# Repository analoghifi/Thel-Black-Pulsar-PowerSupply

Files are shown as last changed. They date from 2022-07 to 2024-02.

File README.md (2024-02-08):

# Thel "Black Pulsar" PowerSupply
Thel High-End "Class-A" Power Supply "Black Pulsar" (correctly: constant current parallel shunt voltage regulator)  

----
  
## Version 2013-2018:
https://web.archive.org/web/20160326152234/http://www.thel-audioworld.de/module/Class-A%20Netzteil/Blackpulsar.htm  
https://web.archive.org/web/20180819093402/http://www.thel-audioworld.de:80/module/Class-A%20Netzteil/Blackpulsar.htm  
  
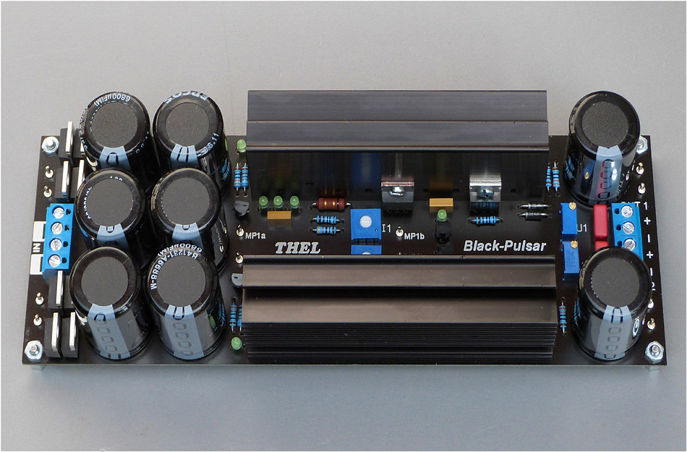
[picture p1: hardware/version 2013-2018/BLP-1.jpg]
  
  
.  
  
## Version 2019:
https://web.archive.org/web/20190630191455/http://thel-audioworld.de/module/Class-A%20Netzteil/Blackpulsar.htm  
  
### 10W:
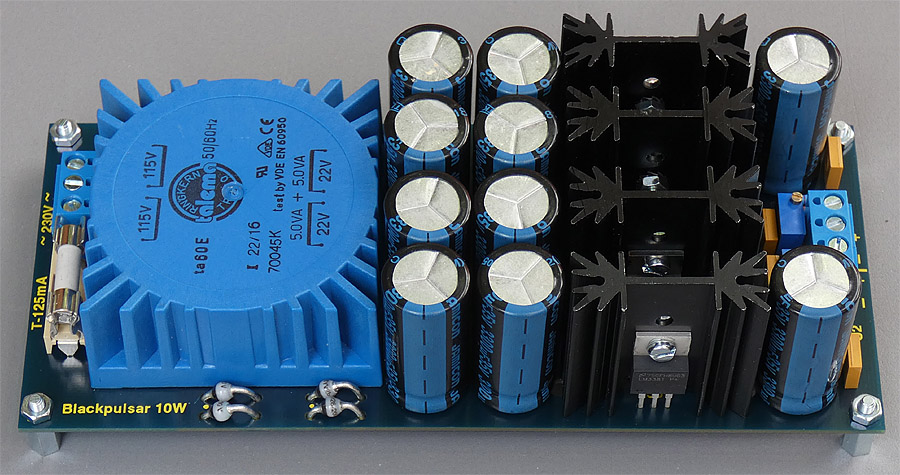
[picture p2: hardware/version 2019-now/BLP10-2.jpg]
  
  
### 25W:
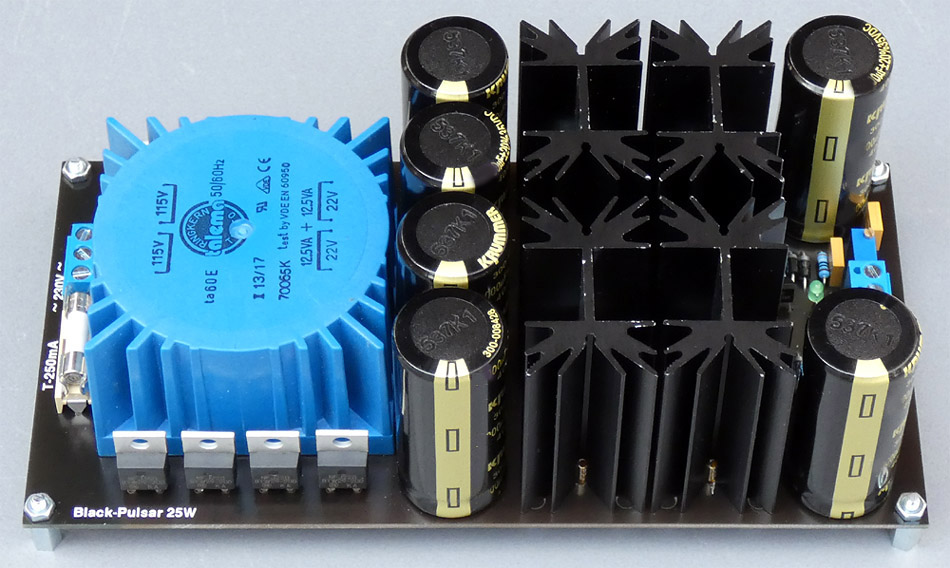
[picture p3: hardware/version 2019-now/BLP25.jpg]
  
  
----  
### Kicad projects in this repo:  
* [version 2013-2018](https://github.com/analoghifi/Thel-Black-Pulsar-PowerSupply/tree/main/hardware/version%202013-2018/KiCad/original) | state: initial release v1.01 | like the original, 1-layer, THT
*  [Black Pulsar 10W](https://github.com/analoghifi/Thel-Black-Pulsar-PowerSupply/tree/main/hardware/version%202019-now/10W/KiCad) (version 2019) | state: coming soon... | like the original, 1-layer, THT
*  [Black Pulsar 25W](https://github.com/analoghifi/Thel-Black-Pulsar-PowerSupply/tree/main/hardware/version%202019-now/25W/KiCad) (version 2019) | state: coming soon... | like the original, 1-layer, THT

----

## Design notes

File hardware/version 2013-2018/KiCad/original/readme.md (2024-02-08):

this is not the original Thel PCB but it's very like\* the original with the following exceptions:  
* more massive ground and power supply PCB tracks  
* using the 2mm gold-plated brass solder pins (the same ones used on the more expensive Thel modules)
* using a combined 5.0mm/7.5mm pin spacing footprint for the foil caps (C7,C14)  
* using a combined 2.5mm/5.0mm pin spacing footprint for the small ceramic caps (C4,C5,C11,C12)  
  
\*(same schematic / same 1-layer\** layout THT / same THT components in the same places on the board)  
\**(strictly speaking, this KiCad PCB is a two-layer PCB with plated-through holes, but you can also (let) produce it as a classic 1-layer PCB with non-plated holes if you wish, since all the tracks are on the bottom side only)  
  
----  
  
these are KiCad 6.x projects  
see how to get the proper 3D-Models from here: https://github.com/analoghifi/KiCad-3D-Models

use kicanvas.org to see this KiCad-Project in your browser:
https://kicanvas.org/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

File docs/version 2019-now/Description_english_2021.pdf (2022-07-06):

basics (https://web.archive.org/web/20210304224601/http://www.thel-audioworld.de/module/Netzteil/Infos.htm)

There are hardly any measurable hum or noise voltages or other interference components at the output. Also, not a single measure to compensate for the tendency to oscillate is necessary, as is often the case with line voltage-regulated power supplies.

Double power
pack The power pack is doubled up, the voltage of both halves can be adjusted separately and can be used individually. For operation on our audio modules, the two outputs are connected in series, which results in the required symmetrical operating voltage (https://web.archive.org/web/20210304224601/http://www.thel-audioworld.de/module/Netzteil/Infos.htm) (eg +/-18V).

weight

As a reward, a hitherto unfulfillable wishful thinking seems to have been achieved - a voltage in battery quality, in terms of freedom from interference and audiophile behavior.

Info on the electrolytic capacitor temperature: The electrolytic capacitors are selected LOW-ESR 105° types. At a cooler temperature of approx. 85° degrees, the electrolytic capacitor temperature levels off at approx. 50° degrees.

internal

audio modules (https://web.archive.org/web/20210304224601/http://www.thel-audioworld.de/module/module.htm)

Waste of energy in its purest form While conventional
analog power supplies only deliver as much current as the consumer draws, the maximum possible current flows constantly here, which is "consumed" by a load resistance and which at the same time keeps the output voltage constant. If the consumer draws current, this is shared with the load resistance, since the same current always flows through the constant current source. This switching principle is comparable to a car that is driven at full throttle and the speed is only controlled with the brakes. As a result, this "waste of energy" causes the power supply's cooler to get very hot, with the temperature dropping as the load draws more current. Since this circuit technology offers very special advantages in terms of power quality, the power supply unit does not have to be significantly oversized.

Consider that the output voltage of an audio circuit is 100% the supply voltage, only modulated by the input signal. This is the only way to realize how important the quality of the power supply is and what unexpected effects such a crazy power supply has.

EUR

For audiophile small consumers, such as preamps, phono preamps, active crossovers, Raspberry Pi, DA converters, audio boards, and much more. The power supply is double, both halves can be adjusted separately.

The increase in performance of the connected high-end audio modules is of such magnitude that the relatively high energy loss seems justified in any case. Preamplifiers, phono preamplifiers, etc. reach their highest level, caused by a voltage purity, as it is only known from rechargeable batteries , and even surpasses it in some values - such as speed.

The maximum output current should not be more than approx. 80% of the internal constant current (see table).

The sketch shows one half of the dual power supply

Connection options see here. (https://web.archive.org/web/20210304224601/http://www.thel-audioworld.de/module/NT-HQ/NT-HQ.htm) A parallel connection as shown in Figure 3 is not possible with the black pulsar (current source).

Type

Housing ventilation
The cooler may reach a temperature of 85°-90° degrees. Ventilation may be necessary if the housing is too small. If in doubt, test. Ventilation could be provided by drilling holes in the floor (below or next to the circuit board) and in the back panel. The circuit board already contains ventilation holes under the coolers.

transformer

an order (https://web.archive.org/web/20210304224601/http://www.thel-audioworld.de/KATALOG/order.htm)

Through the skilful use of appropriate ICs and transistors, this perfected type of circuit is in principle free of any tendency to oscillate and generate noise. Even mains disturbances are effectively suppressed, since a power source for alternating current of any kind represents an almost infinitely high resistance. For the same reason, almost no reverse interference is caused in the mains, since the constant flow of current - apart from the usual current peaks caused by rectification - does not allow any further impulse-like current changes, which is the great misery of switch-mode power supplies. Therefore, a digital consumer on the Black Pulsar, such as a DA converter, Raspberry Pi, etc., causes almost no feedback on the network due to the clocked power consumption.

Short-circuit proof as a matter of principle - also in this case no more than the constant current can flow.

output voltage

Important components are of high audiophile quality: Super-fast rectifier diodes, selected Krummer capacitors (only BLP-25) in their behavior when connected in parallel, temperature behavior, ESR and service life, as well as a straight layout and easy handling.

The internal constant current is fixed. If you want to reduce it, you can increase the value of the built-in resistor intended for this purpose in inverse proportion according to the operating instructions (described in the instructions).

power adapter (https://web.archive.org/web/20210304224601/http://www.thel-audioworld.de/module/Netzteil/Infos.htm)

In view of the relatively high loss values (approx. 3 - 12 watts per half, depending on the module), it is necessary that the matter is well thought out.

Due to the so-called "Class-A" circuit principle (see below), the power supply constantly draws its maximum power from the mains, which means that the cooler gets very warm (approx. 80-90°). In contrast to conventional power supplies, the cooler temperature drops accordingly due to the power consumption of the consumers. Therefore, the power pack gets warmest when there is no load. Of course, the power packs are also operationally safe without a load, even if a high temperature of approx. 80-90°C occurs, depending on the housing ventilation.

Max

T.Hartwig-ELEktronik owner Thomas Hartwig Blumenweg 3a, D-34355 Staufenberg Tel. 05543-3317, email (https://web.archive.org/web/20210304224601/http://www.thel-audioworld.de/Katalog/order.htm) Office hours: Mon-Thu, approx. 2 p.m. - 4 p.m. Ust. ID. No.: (VAT) DE 115268023 Privacy Policy

This enables a puristic use of components, which has a corresponding effect on the liveliness of the music reproduction. Depending on your needs and preferences, unlimited electrolytic capacitor capacities can also follow.

< to the home page (https://web.archive.org/web/20210304224601/http://www.thel-audioworld.de/index.htm)

The Wayback Machine - https://web.archive.org/web/20210304224601/http://www.thel-audioworld.de/module/Class-A%20Netzteil/Blackpulsar.htm Regulated Class-A power supply (shunt power supply ) in battery quality

The exceptional power supply in the audiophile world

Dates /Prices (incl. VAT)

general overview (https://web.archive.org/web/20210304224601/http://www.thel-audioworld.de/module/module.htm)

Black Pulsar "Class A" power supplies in constant current technology with electronic shunt resistor, making them extremely fast.

Were (https://web.archive.org/web/20210304224601/http://www.thel-audioworld.de/KATALOG/order.htm)

## Machine Translated by Google

11V-23V

10VA; 2x09V

126.00

Instruction manual/manual (https://web.archive.org/web/20210304224601/http://www.thel-audioworld.de/module/Class-A%20Netzteil/BLP.GIF)

The designation "Class A"

Anyone who still thinks that the world needs his comment on the sense or nonsense of a Class-A power supply should accept that the tonal advantage is not

3.3V - 7V
BLP25-15

126.00

(BLP-25 Krummer capacitors only).

The sonic successes of such a power pack on correspondingly sensitive circuits and ears can hardly be physically (or scientifically) verified

3.3V-14V
BLP10-22

25VA; 2x22V

The BLP-10's actually equipped electrolytic capacitors may differ from the photos.

Thus, the unofficial designation "Class-A power supply" best describes the functional principle of our power supply series "Black-Pulsar".

23W permanent

shunt resistance. Only when the consumer draws electricity is the energy released to the consumer instead of to the heat sink. In the case of power amplifiers, these are the loudspeakers

adjustable
BLP10-09

25VA; 2x09V

148.00

Dimensions LxWxH: 163x72x40mm

to explain.

10VA; 2x15V

148.00

Input voltage: 230V~
Power consumption: 11W permanent

Constant current
2x360mA
2x210mA
2x135mA

Output current (approx.)
2x300mA 2x170mA
2x110mA

is not a common name for a power supply. It is mainly used in power amplifiers. However, the principle is the same.

490gr
490gr
490gr

The global delivery situation does not always allow the same manufacturer to be used.

3.3V-14V
BLP25-22

126.00

Alternative name: shunt power supply

in the case of power supply units, the connected loads.

you have to prove it - you just know it.

BLP10-15

3.3V - 7V

25VA; 2x15V

11V-23V

BLP25-09 | 900gr 900gr 900gr
148.00

230V~

2x1000mA
2x440mA
2x270mA

2x800mA
2x350mA
2x220mA
Before using
the power packs, set the output voltage to the required value and check it under load in the application.

10VA; 2x22V

182x92x53mm

The maximum current is constantly drawn and converted into heat when not in use. In the case of power amplifiers due to the high quiescent current, in the case of power supply units due to the

Further data | BLP10 .

## BLP25

## Machine Translated by Google

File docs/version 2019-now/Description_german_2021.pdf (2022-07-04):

The Wayback Machine - https://web.archive.org/web/20210304224601/http://www.thel-audioworld.de/module/Class-A%20Netzteil/Blackpulsar.htm

## Geregeltes Class-A Netzteil (Shunt-Netzteil) in Akku-Qualität

T.Hartwig-ELektronik Inh. Thomas Hartwig
Blumenweg 3a, D-34355 Staufenberg Tel. 05543-3317, E-Mail (https://web.archive.org/web/20210304224601/http://www.thel-audioworld.de/Katalog/order.htm)
Bürozeit: Mo-Do, ca. 14.00-16.00 Uhr
Ust. ID. Nr.: (VAT) DE 115268023 Datenschutzerklärung (https://web.archive.org/web/20210304224601/http://www.thel-audioworld.de/DSE.htm)

< zur Startseite (https://web.archive.org/web/20210304224601/http://www.thel-audioworld.de/index.htm)

Gesamtübersicht
Audio-Module (https://web.archive.org/web/20210304224601/http://www.thel-audioworld.de/module/module.htm)

Netzteil
Grundlagen (https://web.archive.org/web/20210304224601/http://www.thel-audioworld.de/module/Netzteil/Infos.htm)

Waren-Bestellung (https://web.archive.org/web/20210304224601/http://www.thel-audioworld.de/KATALOG/order.htm)

### Das Ausnahme-Netzteil in der audiophilen Welt

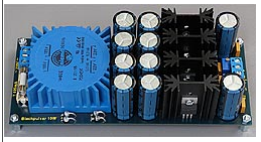
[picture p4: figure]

### Black-Pulsar "Class-A"-Netzteile

in Konstantstromtechnik mit elektronischem Shuntwiderstand, dadurch extrem schnell.
Für audiophile Kleinverbraucher, wie Vorstufen Phonovorstufen, Aktivweichen, Raspberry Pi, DA-Wandler, Audioboards, uvm Das Netzteil ist doppelt aufgebaut, beide Hälften sind getrennt einstellbar.

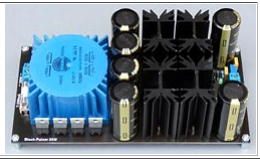
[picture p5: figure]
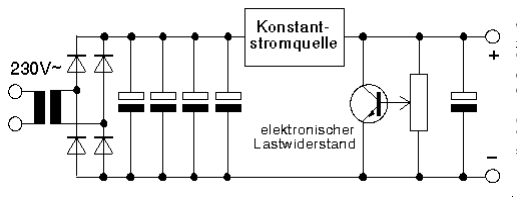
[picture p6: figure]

Energie-Vergeudung in seiner reinsten Form
Während übliche Analog-Netzteile nur so viel Strom liefern, wie der Verbraucher zieht, fließt hier ständig der max mögliche Strom, der von einem Lastwiderstand "verbraucht" wird, und der gleichzeitig die Ausgangsspannung konstant hält. Zieht der Verbraucher Strom, so teilt sich dieser mit dem Lastwiderstand auf, da durch die Konstantstromquelle immer der gleiche Strom fließt. Dieses Schaltungs-Prinzip ist vergleichbar mit einem Auto, das mit Vollgas gefahren und die Geschwindigkeit nur mit der Bremse geregelt wird. Folglich werden durch diese "Energievergeudung" die Kühler des Netzteils sehr heiß, wobei die Temperatur sinkt, je mehr Strom der Verbraucher zieht. Da diese Schaltungstechnik ganz besondere Vorteile in der Stromqualität bietet, muss das Netzteil nicht nennenswert überdimensioniert werden.

Die Skizze zeigt eine Hälfte des Doppelnetzteiles

Angesichts der relativ hohen Verlustwerte (ca. 3 - 12 Watt pro Hälfte, je nach Modul), ist es erforderlich, dass die Sache gut durchdacht ist.
Als Belohnung scheint ein bisher nicht erfüllbares Wunschdenken erreicht worden zu sein - Eine Spannung in Akku-Qualität, was Störungsfreiheit und audiophiles Verhalten betrifft.
Durch geschickten Einsatz entsprechender ICs und Transistoren ist diese perfektionierte Schaltungsart prinzipiell frei von jeglicher Schwing- und Rauschneigung. Sogar Netzstörungen werden wirkunsvoll unterdrückt, da eine Stromquelle für Wechselstrom jeder Art einen nahezu unendlich hohen Widerstand darstellt. Aus dem gleichen Grund werden auch so gut wie keine Rückwärts-Störungen ins Netz verursacht, da der konstante Stromfluss - außer durch die üblichen Stromspitzen durch die Gleichrichtung - keine weiteren impulsartigen Strom-Änderungen zulässt, was ja gerade bei Schaltnetzteilen das große Elend ist. Daher verursacht ein digitaler Verbraucher am Black-Pulsar, wie z.B. DA-Wandler, Raspberry Pi, usw., durch den getakteten Stromverbrauch so gut wie keine Rückwirkung ins Netz.
Am Ausgang sind kaum messbare Brumm- oder Rauschspannungen oder andere Störanteile vorhanden. Auch ist keine einzige Kompensations-Maßnahme gegen Schwingneigung erforderlich, wie sie oft bei längs-spannungsgeregelten Netzteilen üblich ist.

Das ermöglicht einen puristischen Bauteile-Einsatz, was sich entsprechend auf die Lebendigkeit der Musikwiedergabe auswirkt. Auch können je nach Bedarf und Vorliebe unbegrenzte Elkokapazitäten folgen.

Die Performance-Steigerung angeschlossener High-End Audiomodule ist von solchem Ausmaß, dass der relativ hohe Energieverlust auf jeden Fall gerechtfertigt erscheint. Vorstufen, Phonovorstufen, usw. erreichen ihr höchstes Level, hervorgerufen durch eine Spannungsreinheit, wie sie bisher nur von Akkus bekannt ist, und diese sogar in einigen Werten - wie z.B. Schnelligkeit - noch übertrifft.

Wichtige Bauteile sind von hoher audiophiler Qualität: Superschnelle Gleichrichterdioden, ausgesuchte Elkos der Fa. Krummer-Kondensatoren (nur BLP-25) im Verhalten bei Parallelschaltung, Temperaturverhalten, ESR und Lebensdauer, sowie geradliniges Layout und einfache Handhabung.

Man bedenke, dass die Ausgangsspannung einer Audioschaltung zu 100% aus der Versorgungsspannung besteht, lediglich moduliert vom Eingangssignal. Erst dadurch mag bewusst werden, wie wichtig die Qualität der Stromversorgung ist und welch ungeahnte Auswirkungen ein solch abgefahrenes Netzeil besitzt.

Gehäusebelüftung
Der Kühler darf eine Temperatur von 85°-90° Grad erreichen. Bei einem zu kleinen Gehäuse könnte eine Belüftung nötig sein. Im Zweifel testen. Eine Belüftung könnte mittels Bohrlöcher im Boden (unter oder neben der Leiterplatte) und in der Rückwand angebracht werden. Die Leiterplatte enthält bereits Belüftungslöcher unter den Kühlern.
Info zur Elkotemperatur: Die Elkos sind ausgesuchte LOW-ESR 105° Typen. Bei ca. 85° Grad Kühlertemperatur pendelt sich die Elkotemperatur bei ca. 50° Grad ein.

Kurzschlussfest aus Prinzip - auch in diesem Falle kann nicht mehr, als der Kontantstrom fließen.

Doppelnetzteil
Das Netzteil ist doppelt aufgebaut, beide Hälften sind getrennt in der Spannung einstellbar und können einzeln verwendet werden. Für den Betrieb an unseren Audiomodulen werden die beiden Ausgänge in Reihe geschalten, wodurch man die erforderliche symmetrische Betriebsspannung (https://web.archive.org/web/20210304224601/http://www.thel-audioworld.de/module/Netzteil/Infos.htm) (z.B. +/-18V) erhält. Anschlussmöglichkeiten siehe hier. (https://web.archive.org/web/20210304224601/http://www.thel-audioworld.de/module/NT-HQ/NT-HQ.htm) Eine Parallelschaltung wie Bild 3 ist beim Black-Pulsar (Stromquelle) nicht möglich.

Bedingt durch das sogenannte "Class-A" Schaltungsprinzip (siehe weiter unten), nimmt das Netzteil ständig seine Maximalleistung aus dem Netz auf, wodurch die Kühler sehr warm werden (ca. 80-90°). Im Gegensatz zu konventionellen Netzteilen sinkt durch die Stromentnahme der Verbraucher die Kühler-Temperatur entsprechend. Daher wird das Netzteil am wärmsten, wenn keine Last entnommen wird
Natürlich sind die Netzteile auch ohne Last betriebssicher, auch wenn dabei eine hohe Temperatur von ca. 80-90°, je nach Gehäusebelüftung, entsteht.
Der max. Ausgangsstrom sollte nicht mehr als ca. 80% des internen Konstantstromes betragen (s. Tabelle).

Der interne Konstantstrom ist fest eingestellt. Wer ihn reduzieren möchte, kann den dafür bestimmten eingebauten Widerstand gemäß der Bedienungsanleitung umgekehrt proportional im Wert vergrößern (wird in der Anleitung beschrieben).

### Daten/Preise (inkl. Mwst)

Typ | Trafo | interner | max | Ausgangsspannung | Gewicht | EUR

| | Konstantstrom | Ausgangsstrom (ca.) | einstellbar
BLP10-09 | 10VA; 2x09V | 2x360mA | 2x300mA | 3,3V - 7V | 490gr | 126,00
BLP10-15 | 10VA; 2x15V | 2x210mA | 2x170mA | 3,3V -14V | 490gr | 126,00
BLP10-22 | 10VA; 2x22V | 2x135mA | 2x110mA | 11 V- 23V | 490gr | 126,00
BLP25-09 | 25VA; 2x09V | 2x1000mA | 2x800mA | 3,3V - 7V | 900gr | 148,00
BLP25-15 | 25VA; 2x15V | 2x440mA | 2x350mA | 3,3V -14V | 900gr | 148,00
BLP25-22 | 25VA; 2x22V | 2x270mA | 2x220mA | 11 V- 23V | 900gr | 148,00
| | | Achtung
vor dem Einsatz der Netzteile die Ausgangsspannung auf den erforderlichen Wert einstellen und in der Anwendung unter Last prüfen.
| | Weitere Daten | BLP10 | BLP25

Bedienungsanleitung/Manual (https://web.archive.org/web/20210304224601/http://www.thel-audioworld.de/module/Class-A%20Netzteil/BLP.GIF)

Eing.Spg.: 230V~ | 230V~
Leistungsaufnahme: 11W permanent | 23W permanent
Maße LxBxH: 163x72x40mm | 182x92x53mm

Die tatsächlich bestückten Elkos des BLP-10 können von den Fotos abweichen. Die weltweite Liefersituation lässt es nicht zu, dass immer der gleiche Hersteller eingesetzt werden kann. (BLP-25 ausschließlich Krummer-Kondensatoren).

Die Bezeichnung "Class-A"
ist keine gängige Bezeichnung für ein Netzteil. Sie wird hauptsächlich bei Endstufen verwendet. Das Prinzip ist jedoch gleich. Es wird ständig der maximale Strom gezogen und bei bei Nichtgebrauch in Wärme umgesetzt. Bei Endstufen durch den hohen Ruhestrom, bei Netzteilen durch den Shuntwiderstand. Erst wenn der Verbraucher Strom zieht, wird die Energie statt in die Kühlkörper an den Verbraucher abgegeben. Bei Endstufen sind das die Lautsprecher bei Netzteilen die angeschlossenen Verbraucher. Somit beschreibt die nicht offizielle Bezeichnung "Class-A Netzteil" am besten das Funktionsprinzip unserer Netzteilserie "Black-Pulsar". Alternative Bezeichnung: Shunt-Netzteil

Die klanglichen Erfolge eines solchen Netzteiles an entsprechend sensiblen Schaltungen und Ohren kann man physikalisch (oder wissenschaftlich) tatsächlich kaum erklären.
Wer dennoch meint, über Sinn oder Unsinn eines Class-A Netzteiles benötige die Welt seinen Kommentar, der sollte akzeptieren, dass man den klanglichen Vorteil nicht beweisen muss - man weiß es einfach.

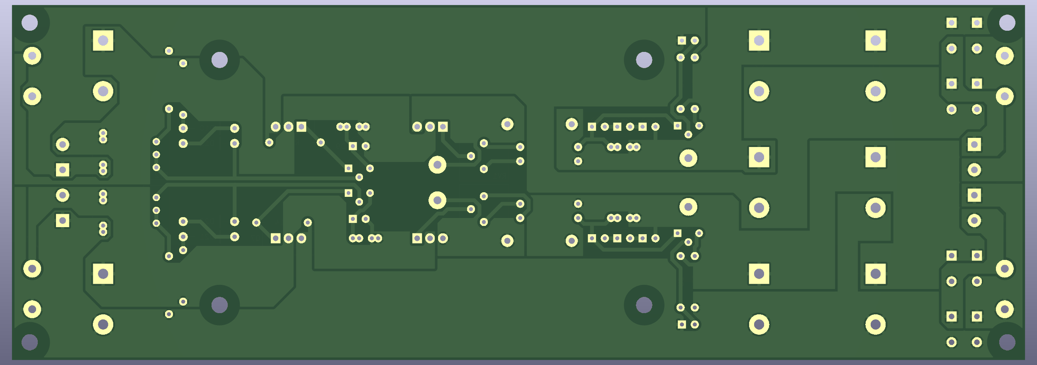
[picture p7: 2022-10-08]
hardware/version 2013-2018/KiCad/original/black_pulsar_2013-18_original_1Layer_THT__bottom.png

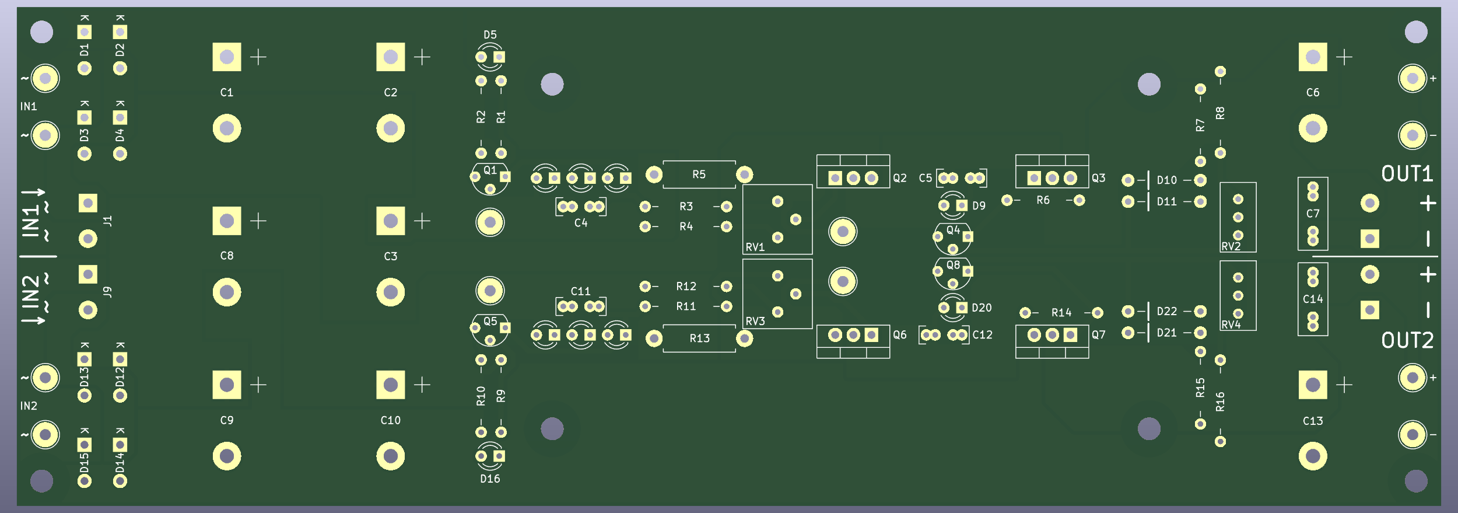
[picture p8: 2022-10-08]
hardware/version 2013-2018/KiCad/original/black_pulsar_2013-18_original_1Layer_THT__top.png

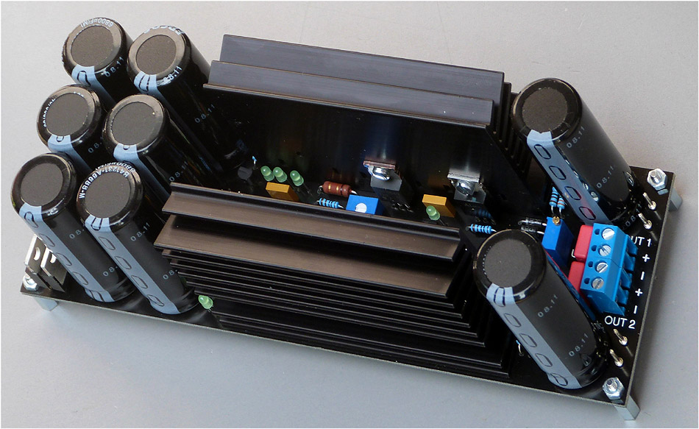
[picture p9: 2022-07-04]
hardware/version 2013-2018/BLP-3.jpg

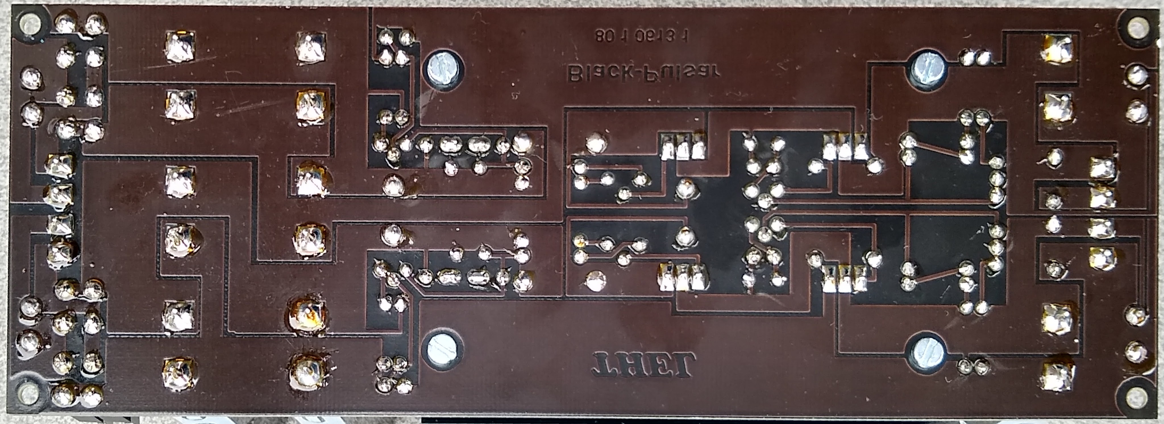
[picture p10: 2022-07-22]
hardware/version 2013-2018/Black_pulsar_2013-2018_bottom_mirror.jpg

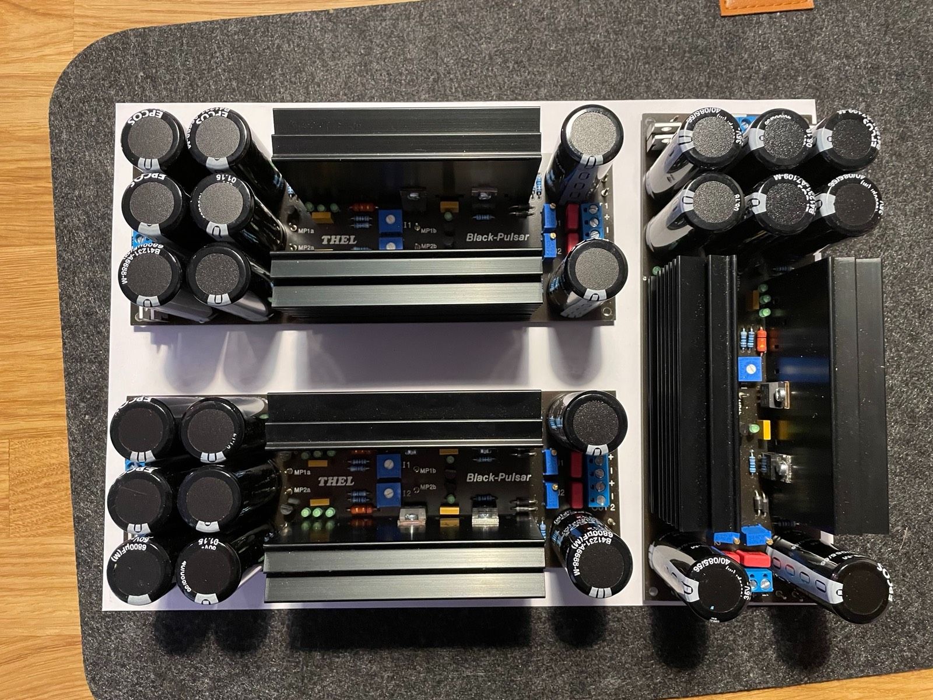
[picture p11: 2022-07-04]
hardware/version 2013-2018/black_pulsar_2013-2018_1.jpg

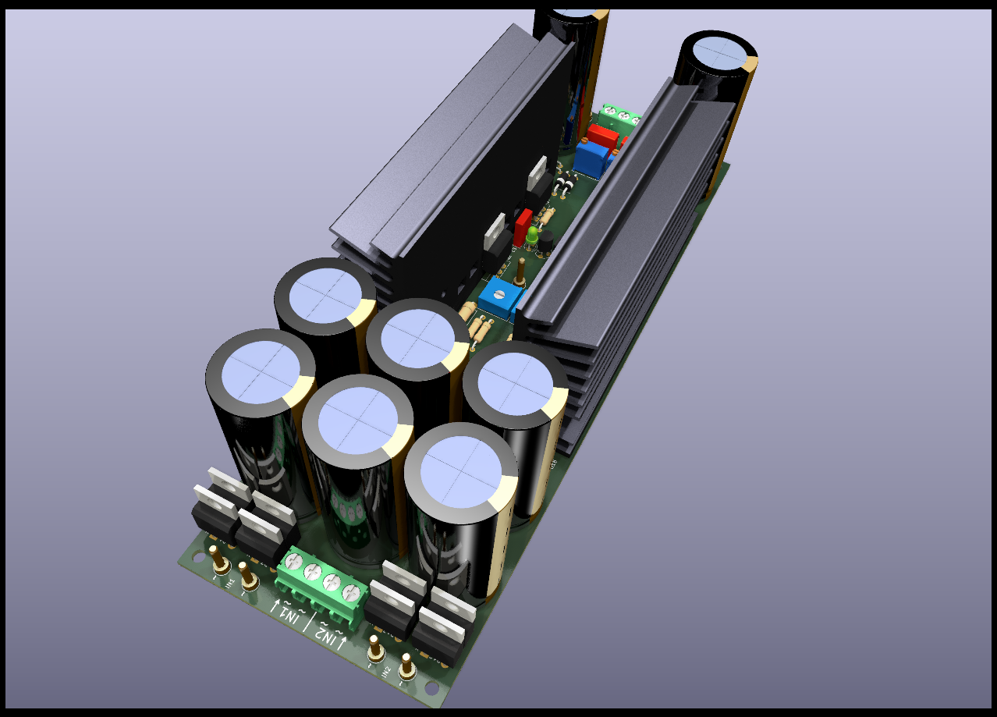
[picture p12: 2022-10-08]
hardware/version 2013-2018/KiCad/original/black_pulsar_2013-18_original_1Layer_THT__3D_1.png

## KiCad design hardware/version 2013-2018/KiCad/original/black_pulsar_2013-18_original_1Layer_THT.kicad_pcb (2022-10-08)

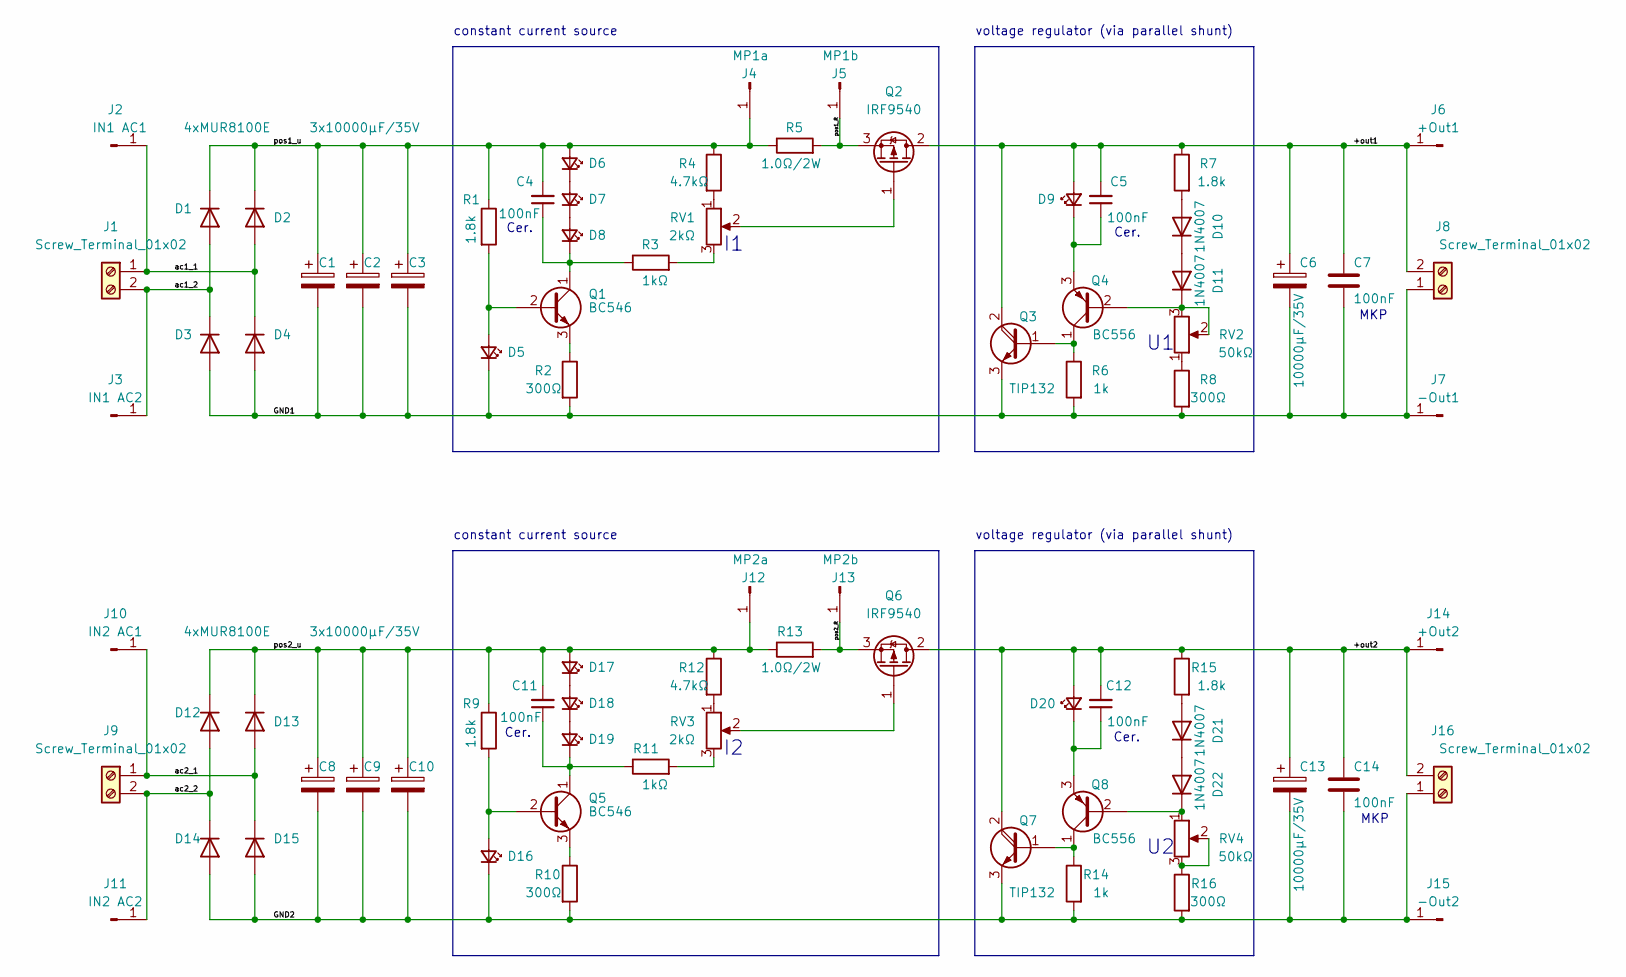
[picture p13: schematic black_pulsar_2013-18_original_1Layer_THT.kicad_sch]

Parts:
C1, C8: 3x10000µF/35V; CP_Radial_D22_H50_P10.00mm_SnapIn_min_silk
C2, C3, C9, C10: 2200µF; CP_Radial_D22_H50_P10.00mm_SnapIn_min_silk
C4, C5, C11, C12: 100nF; C_Rect_L7.0mm_W2.5mm_P2.50_5.00mm_min_silk
C6, C13: 10000µF/35V; CP_Radial_D22_H50_P10.00mm_SnapIn_min_silk
C7, C14: 100nF; C_Rect_L10.0mm_W4.0mm_P5.00_P7.50mm
D1, D12: 4xMUR8100E; TO-220-2_Vertical_noSilk
D2, D3, D4, D13, D14, D15: BYW29-200; TO-220-2_Vertical_noSilk
D5, D6, D7, D8, D9, D16, D17, D18, D19, D20: LED_Small; LED_D3.0mm
D10, D11, D21, D22: 1N4007; D_DO-41_SOD81_P10.16mm_Horizontal_minSilk
J1, J8, J9, J16: Screw_Terminal_01x02; TerminalBlock_Phoenix_PT-1,5-2-5.0-H_1x02_P5.00mm_Horizonta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
J2: IN1 AC1; Loet_Pin_D1.5mm_L14.0mm
J3: IN1 AC2; Loet_Pin_D1.5mm_L14.0mm
J4: MP1a; Loet_Pin_D1.5mm_L14.0mm
J5: MP1b; Loet_Pin_D1.5mm_L14.0mm
J6: +Out1; Loet_Pin_D1.5mm_L14.0mm
J7: -Out1; Loet_Pin_D1.5mm_L14.0mm
J10: IN2 AC1; Loet_Pin_D1.5mm_L14.0mm
J11: IN2 AC2; Loet_Pin_D1.5mm_L14.0mm
J12: MP2a; Loet_Pin_D1.5mm_L14.0mm
J13: MP2b; Loet_Pin_D1.5mm_L14.0mm
J14: +Out2; Loet_Pin_D1.5mm_L14.0mm
J15: -Out2; Loet_Pin_D1.5mm_L14.0mm
Q1, Q5: BC546; TO-92_wide
Q2, Q6: IRF9540; TO-220-3_Vertical
Q3, Q7: TIP132; TO-220-3_Vertical
Q4, Q8: BC556; TO-92_wide
R1, R7, R9, R15: 1.8k; R_Axial_DIN0207_L6.3mm_D2.5mm_P10.16mm_Horizontal_minSilk
R2, R10: 300Ω; R_Axial_DIN0207_L6.3mm_D2.5mm_P10.16mm_Horizontal_minSilk
R3, R11: 1kΩ; R_Axial_long_L6.3mm_D2.5mm_P11.43mm_Horizontal_minSilk
R4, R12: 4.7kΩ; R_Axial_long_L6.3mm_D2.5mm_P11.43mm_Horizontal_minSilk
R5, R13: 1.0Ω/2W; R_Axial_DIN0411_L9.9mm_D3.6mm_P12.70mm_Horizontal
R6, R14: 1k; R_Axial_DIN0207_L6.3mm_D2.5mm_P10.16mm_Horizontal_minSilk
R8, R16: 300Ω; R_Axial_long_L6.3mm_D2.5mm_P11.43mm_Horizontal_minSilk
RV1, RV3: 2kΩ; Potentiometer_Bourns_3386P_Vertical
RV2, RV4: 50kΩ; Potentiometer_Bourns_3296W_Vertical

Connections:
/+out1: C5.2, C6.1, C7.1, D9.2 (A), J6.1, J8.2, Q2.2 (D), Q3.2 (C), R7.1
/+out2: C12.2, C13.1, C14.1, D20.2 (A), J14.1, J16.2, Q6.2 (D), Q7.2 (C), R15.1
/GND1: C1.2, C2.2, C3.2, C6.2, C7.2, D3.2 (A), D4.2 (A), D5.1 (K), J7.1, J8.1, Q3.3 (E), R2.2, R6.2, R8.2
/GND2: C8.2, C9.2, C10.2, C13.2, C14.2, D14.2 (A), D15.2 (A), D16.1 (K), J15.1, J16.1, Q7.3 (E), R10.2, R14.2, R16.2
/ac1_1: D2.2 (A), D4.1 (K), J1.1, J2.1
/ac1_2: D1.2 (A), D3.1 (K), J1.2, J3.1
/ac2_1: D13.2 (A), D15.1 (K), J9.1, J10.1
/ac2_2: D12.2 (A), D14.1 (K), J9.2, J11.1
/pos1_R: J5.1, Q2.3 (S), R5.2
/pos1_u: C1.1, C2.1, C3.1, C4.2, D1.1 (K), D2.1 (K), D6.2 (A), J4.1, R1.1, R4.1, R5.1
/pos2_R: J13.1, Q6.3 (S), R13.2
/pos2_u: C8.1, C9.1, C10.1, C11.2, D12.1 (K), D13.1 (K), D17.2 (A), J12.1, R9.1, R12.1, R13.1
unnamed: C4.1, D8.1 (K), Q1.1 (C), R3.1
unnamed: C5.1, D9.1 (K), Q4.3 (E)
unnamed: C11.1, D19.1 (K), Q5.1 (C), R11.1
unnamed: C12.1, D20.1 (K), Q8.3 (E)
unnamed: D5.2 (A), Q1.2 (B), R1.2
unnamed: D6.1 (K), D7.2 (A)
unnamed: D7.1 (K), D8.2 (A)
unnamed: D10.1 (K), D11.2 (A)
unnamed: D10.2 (A), R7.2
unnamed: D11.1 (K), Q4.2 (B), RV2.2, RV2.3
unnamed: D16.2 (A), Q5.2 (B), R9.2
unnamed: D17.1 (K), D18.2 (A)
unnamed: D18.1 (K), D19.2 (A)
unnamed: D21.1 (K), D22.2 (A)
unnamed: D21.2 (A), R15.2
unnamed: D22.1 (K), Q8.2 (B), RV4.1
unnamed: Q1.3 (E), R2.1
unnamed: Q2.1 (G), RV1.2
unnamed: Q3.1 (B), Q4.1 (C), R6.1
unnamed: Q5.3 (E), R10.1
unnamed: Q6.1 (G), RV3.2
unnamed: Q7.1 (B), Q8.1 (C), R14.1
unnamed: R3.2, RV1.3
unnamed: R4.2, RV1.1
unnamed: R8.1, RV2.1
unnamed: R11.2, RV3.3
unnamed: R12.2, RV3.1
unnamed: R16.1, RV4.2, RV4.3

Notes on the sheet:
MKP
voltage regulator (via parallel shunt)
Cer.
constant current source

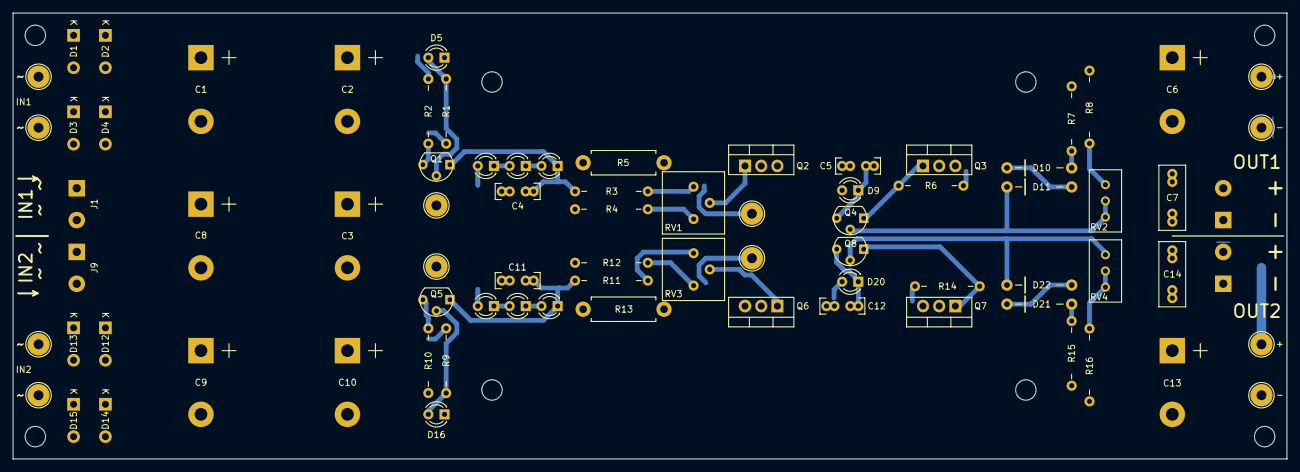
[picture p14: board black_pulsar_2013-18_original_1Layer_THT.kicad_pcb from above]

Board: 2 copper layers, 200.0 x 70.0 mm, 80 parts (0 on the bottom side), 40 nets.
